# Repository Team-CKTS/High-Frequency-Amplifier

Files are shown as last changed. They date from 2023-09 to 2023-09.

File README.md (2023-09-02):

# High-Frequency-Amplifier
During our 3rd semester at the University of Moratuwa, we designed a High-Frequency Amplifier. Croos, Tharusha, Sasini, and Kumudu, who contribute to our team, were able to use their knowledge in circuit design, PCB design, and enclosure design to produce this device resulting in an amplifier capable of driving an 8-ohm load (speaker) without introducing any distortion to the output signal. It can amplify signals ranging from 20kHz to 100kHz, employing a two-stage amplifier approach with specific configurations.



What you can find here :
- Components
- Circuit Design
- PCB Design
- Enclosure Design
- Simulation Results

## Objective ##
The primary objective of this project is to design a high-frequency amplifier with the following specifications:
- **Load Compatibility:** Capable of driving an 8-ohm load (speaker) without causing distortion in the output signal.
- **Frequency Range:** Amplify signals within the frequency range of 20kHz to 100kHz.
- **Amplification Stages:** Utilize a two-stage amplifier approach. The first stage employs a transistor in the common emitter configuration, while the second stage uses an AB Push-Pull 
  amplifier configuration to achieve the necessary power amplification.

## Components ##
- BC547BG NPN BJT transistor
- TIP31C and TIP32C power transistors
- Capacitors, Resistors, Power resistors
- PCB
- Enclosure

## Circuit Design ##
Our circuit was design using **Multism**. It incorporates two amplifier stages. The first stage utilizes a transistor in the common emitter configuration, while the second stage employs an AB Push-Pull amplifier configuration. This combination ensures efficient high-frequency signal amplification.



## PCB Design ##
The PCB design we designed using **Altium Software**. It is essential for achieving reliable and precise circuit connections. It minimizes interference and supports efficient signal amplification. The "PCB design files" directory contains the PCB design files, which include:
- Schematic Design
- PCB Design
- Gerber files for manufacturing





## Enclosure Design ##
We designed an enclosure useing **Solidworks software**, to protecting the amplifier components.





## Contributors ##
- Croos : Circuit	design, Soldering	PCB, Breadboard	Implementation
- Tharusha : Circuit	design, PCB	design, Component Selection
- Sasini : Circuit	design, Enclosure design, Simulation	in Multisim
- Kumudu : Circuit design, Enclosure design, Documentation

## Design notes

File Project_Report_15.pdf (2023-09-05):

## Department of Electronic and Telecommunication Engineering University of Moratuwa

## EN2091 - Laboratory Practice and Projects


## High Frequency Amplifier

## Group 15

Croos J.J.S.E | 200095V
Kaushalya K.W.K | 200298V
Pathirana K.P.T.R | 200449L
Wanigathunga W.A.S.S | 200693D

Abstract

The design of a high frequency amplifier was the objective of this project. This should be able to drive an 8-ohm load(speaker) without causing any distortion to the output signal. It should be able to amplify signals of frequencies 20kHz-100kHz. There are two-stage amplifiers. The first stage uses a transistor in the common emitter configuration. The second stage uses an AB Push Pull amplifier configuration to achieve the power amplification needed to drive the speaker.
The amplifier achieved an open terminal voltage gain of around 20.4, and had a voltage gain of around 14.6 with a speaker.

## Contents

1 Introduction | 2
2 Methodology | 2
3 Results | 5
4 Individual contributions | 8
5 Conclusion | 8
6 References | 8
7 Appendices | 9

## 1 Introduction

This report outlines the challenge that has been assigned as well as the project’s objective requirements.

### 1.1 Objective

The given task is to design a high frequency amplifier with small amplitude loss or waveform distortion that can drive a small speaker. Design requirements for amplifier :

1. Bandwidth: 20 kHz - 100 kHz
2. Minimum number of transistors: 3
3. Operating voltage: < 12V
4. Input: 0.1Vp-p (MAX)
5. It should be able to drive 8 Ω (headphone) load without significant waveform distortion or amplitude reduction.

The parameters to be determined for the specifications sheet for the product :

1. Open Circuit Gain
2. Gain (with 8Ω load)
3. Bandwidth
4. Input Resistance
5. Output Resistance
6. Maximum Load Current

### 1.2 Summary of report

The High Frequency Amplifier design, development, and testing processes are covered in the report.
There are two stages of amplifier, a voltage amplification stage and a power amplification stage.
The amplifier circuit was first sketched up on paper, then it was simulated using Multisim, and then a physical prototype was created and tested using Altium.
Using data from testing performed on the final prototype, the final specifications sheet was created.

## 2 Methodology

The method used to create and design the amplifier is described in this section. Before examining the design method, the amplifier’s theory will be reviewed.

### 2.1 Amplifier Theory

In the market, amplifiers are frequently employed. They have many different applications. The amplification of audio signals before they are sent to speakers is one such application. Whereas the amplifier just has to be able to handle signals up to roughly 20kHz for typical applications dealing with music or voice. Nonetheless, some applications might call for amplification of higherfrequency signals. As a result, a high frequency amplifier’s design is important.

### 2.1.1 Amplifier Classes

Depending on their range of action, amplifiers can be divided into different classes.

### 2.1.2 Class A Amplifiers

The most popular amplifiers are class A amplifiers. They fully amplify the input signal and feature a basic structure. A constant current must flow through the transistor to bias it in a way that prevents it from turning off throughout the oscillation. Nevertheless, because of this characteristic, they are efficient and produce a lot of heat. They cannot, therefore, be applied for high power amplification applications.

### 2.1.3 Class B Amplifiers

Due to bias, only half of the input signal is conducted by class B amplifiers. The complete waveform can be obtained by using

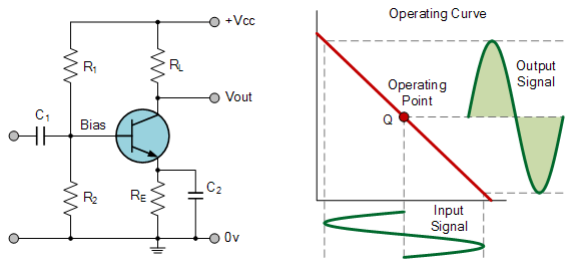
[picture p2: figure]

Figure 1: Class A amplifier

two of these amplifiers set up in a ”Push Pull” arrangement and combining the output signal.
As this amplifier’s quiescent current is 0, there is minimal or no DC current and hence significantly less power loss. Although the 0.7V needed to bias the transistor into the active region causes a small waveform distortion known as zerocrossing distortion, it is still present.

### 2.1.4 Class AB Amplifiers

By permanently bringing the two transistors just inside the active region, class AB amplifiers get over the distortion problem that plagues class B amplifiers. Although the efficiency is decreased, the output waveform is undistorted as a result.

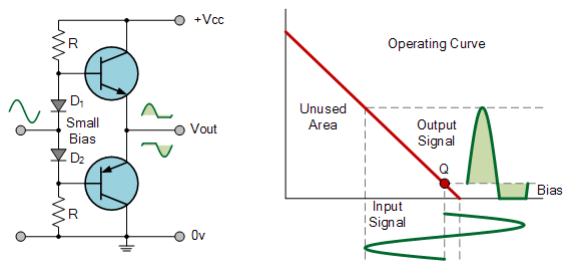
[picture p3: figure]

Figure 2: Block of circuit diagram

Although the power dissipation due to the DC component is substantially smaller than class A amplifiers, this is much more suitable for high power amplification applications.

### 2.2 Circuit Design

The design makes use of a cascading two-stage amplifier. Initially, a Bipolar Junction Transistor is used. It is applied in a common emitter arrangement. A capacitor is used to cascade the amplifier. Four BJTs set up in an AB push pull arrangement are used in the second stage.
The amplifier is cascaded as following manner:

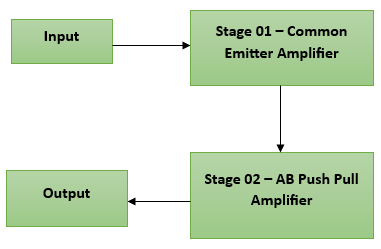
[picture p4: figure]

Figure 3: Block of circuit diagram

A 100µF capacitor connects the two stages in order to stop the transmission of Direct Current (DC) signals.
A 4.7µF capacitor and a small 2.2kΩ resistor are used to connect the input to stage one in order to reduce the distortions that were detected during testing.
For the same reason as previously, a 1000µF capacitor is used to connect the output. This is crucial because DC signals that are transmitted into speakers run the risk of doing so.

### 2.2.1 Stage 01 - Common Emitter

The objective of the first stage is getting a high voltage amplification. Then we decided to use class A common emitter amplifier for this purpose. We got 22 of voltage gain roughly. We used BC547BG transistor after comparing with others.
Higher bandwidth and fast switching, enabling it to handle high frequency signals are the main reasons to select this transistor.
The design of the first stage was determined as follows:

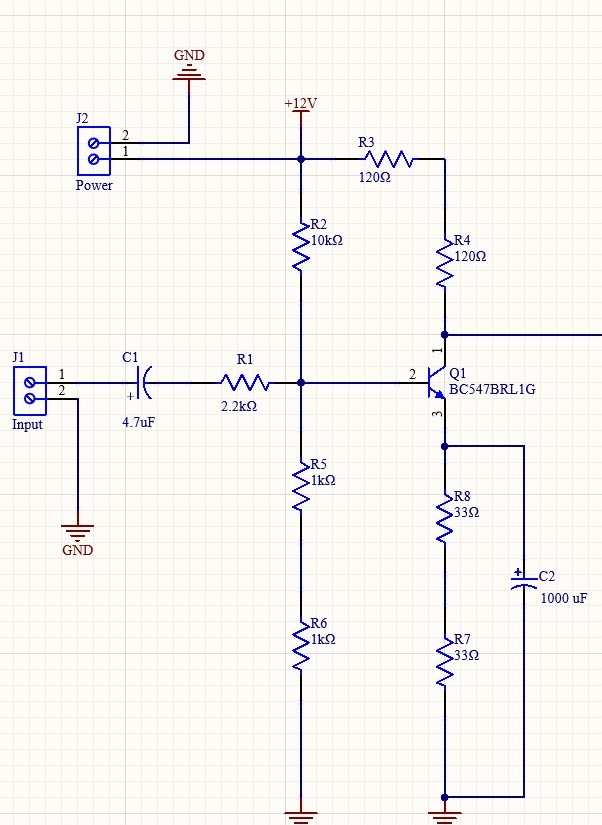
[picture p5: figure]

Figure 4: Stage 1 Circuit Diagram

- The base was biased at the base voltage is 2V. Therefore the base resistors, R2=10kΩ and R5=R6=1kΩ.
- VB = 2V. (Base current is negligible)
- VE = 1.3V. (Assuming VBE is equal to 0.7V)
- We selected the emitter resistor such that Ie ≈ 20 mA.
- Therefore, RE = 66Ω (R7 + R8), IC ≈ 20mA.
- VCE ≈ 6V.
- Therefore, RC =
12−7.3
20 kΩ ≈ 240Ω
(R3 + R4).

### 2.2.2 Stage 02 – AB Push Pull Am-

plifier

AB Push Pull stage is the second stage of amplifier. This stage is used to obtain the necessary power amplification for driving the 8 ohm load (speaker) without significantly reducing the output amplitude.
We made the decision to select the TIP 31C/TIP 32C power transistor pair after reviewing the datasheets. These transistors are capable of handling the high currents that are currently flowing through them and provide a sizable current gain.

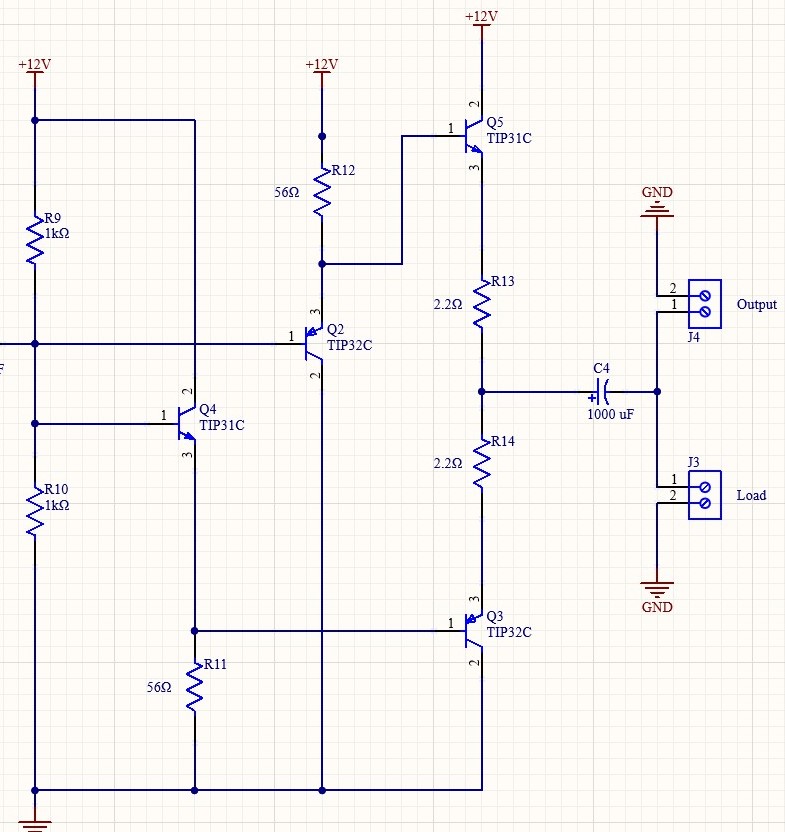
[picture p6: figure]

Figure 5: Stage 2 Circuit Diagram

Because of the high currents flowing through them, the 56Ω resistors are power resistors. The circuit has a large current gain but
a voltage gain of one, which is sufficient for the application.
To guarantee that no DC component reaches the output, the load is connected via a capacitor.

### 2.2.3 Initial Designs

An emitter follower amplifier was used in the early design of the amplifier to create three stages, including a middle current amplification stage. However, this step generated a distortion, and after it was removed, the voltage gain did not decrease. As a result, we choose to eliminate this stage. The base resistors’ initial values were substantially lower (1kΩ and 200Ω). However, when a load was attached, there was an input distortion because of the low input resistance. As a result, we multiplied the input resistors by 10.
Finally, when a load was connected, there was a small distortion of the output signal. We connected a 2.2kΩ resistor in series with the input coupling capacitor to solve this problem.

### 2.3 Prototype Design

Multisim, which was used to create the virtual prototype (see Appendix A), was the foundation for several of the testing. Using Altium, the PCB for the physical prototype was created (See Appendix B for layout). Following screen printing (Figure 6), the necessary parts were soldered to the PCB.

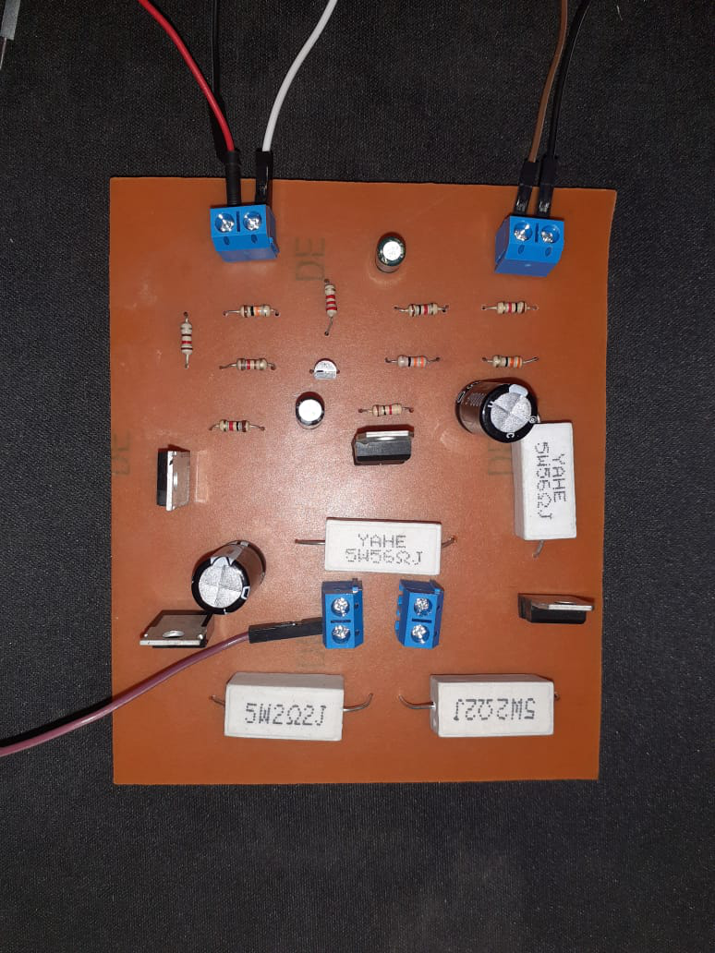
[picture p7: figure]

Figure 6: PCB

SolidWorks was used to create the Enclosure. To allow for heat dissipation and prevent the amplifier from overheating, the enclosure has a perforated cover (see Appendix C).

### 2.3.1 List of Components and Equip-

ment Used

The list of components used in the circuit:

1. BC547BG NPN BJT transistor
2. TIP31C power transistor (2)
3. TIP32C power transistor (2)
4. Heat Sinks (4)
5. Capacitors (4.7uF – 1, 100uF – 1, 1000uF – 2)
6. Resistors (33Ω - 2, 120Ω - 2, 1kΩ - 4, 10kΩ - 1, 2.2kΩ - 1)
7. Power resistors (56Ω - 2, 2.2Ω - 2)

The list of other components and equipment used in the development process:

1. Breadboard
2. Digital Multimeter
3. Power supply
4. Signal Generator
5. Digital Oscilloscope
6. 8Ω speaker
7. Connectors
8. Materials required for screen printing and soldering the PCB

## 3 Results

Three steps made up the evaluation of the amplifier, with the first step being the basic calculations made by hand during circuit design. The simulation of the circuit was second and the prototype was eventually constructed and tested.
Requirements and methods used to test:

### 3.1 Testing and Results

The design requirements were examined and the parameters required for the datasheet were obtained using the actual prototype and the simulation.
The methods of obtaining those parameters are given below.

Design Require-ment | Testing Method
Bandwidth | Simulation
Min No. of tran-sistors | Simulation / Cir-cuit Design
Operating Voltage | Initial Calcula-tions
Allowable Input Voltage | Prototype
Allowable load without distortion | Prototype
Data sheet | Prototype / Simu-lation

### 3.1.1 Initial Calculations

The Hybrid model was initially used to generate some of the parameters for stage one. However , lot of these parameters were eventually discarded because they did not match the observed values.
For the first stage:
Find rπ:

rπ =

VT
IB

=

26mV
20mA/300

= 390Ω

Input resistance:

Rin = Rb1//Rb2//rπ ≈ rπ = 390Ω

Open circuit voltage gain:

Avo ≈

β ∗ Rc

Rin

≈ 180 ≈ 22.55dB

### 3.1.2 Simulation

Multisim was used to simulate the amplifier circuit. The following are the parameters that the simulation obtained:

1. Open circuit gain - 18.986 dB The oscilloscope tool in Multisim was used to test the Open circuit gain. As seen in Figure 7, the value mentioned above is accurate for the mid frequency values.
2. Gain with 8Ω load - 17.167dB By placing an 8Ω load across the output, the gain with an 8Ω load was

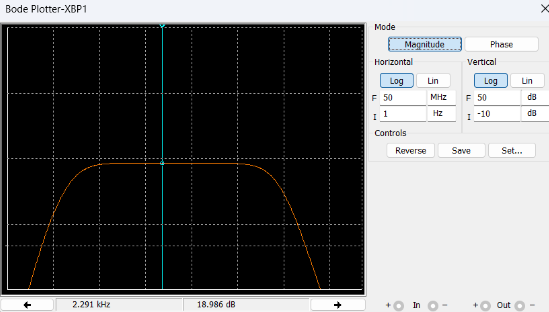
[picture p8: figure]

Figure 7: Bode plot of simulated circuit

evaluated. Then the oscilloscope tool was used to test the gain.

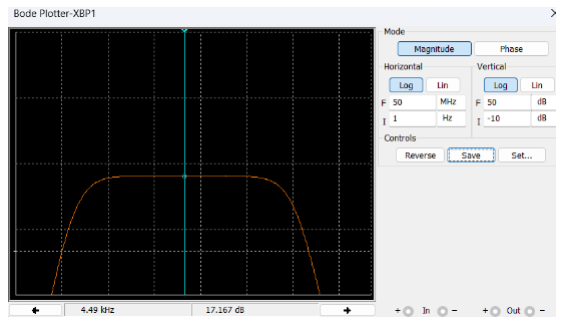
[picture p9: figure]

Figure 8: Bode plot of simulated circuit with 8Ω load

3. Bandwidth – 19.302 Hz to 1.117 MHz
The bode plotter tool which is available in the Multism was used to test the bandwidth of amplifier. Cutoff frequencies were taken as the half power points.
4. Input Resistance – 2.772kΩ
The multimeter was used to test the input resistance for measure the current drawn from the source.
5. Output Resistance – 8.44Ω
The input circuit was shorted to measure the output resistance. Then connecting a current source across the output and using the multimeter to measure the voltage across the output.
6. Maximum Load Current
– 31.6mA (for 8Ω load)

The multimeter was used to measure the current through the load

### 3.1.3 Tested Circuit

The Prototype Amplifier was tested, and the results revealed the following useful parameters.

1. Open Circuit Voltage Gain
– 13.096dB
By attaching the input and output to an oscilloscope and determining the voltage gain between the two, the open circuit gain was evaluated. The voltage gain was evaluated for frequencies between 20Hz and 100kHz, and the value above is the highest voltage gain that was consistently present throughout the mid-frequency ranges.

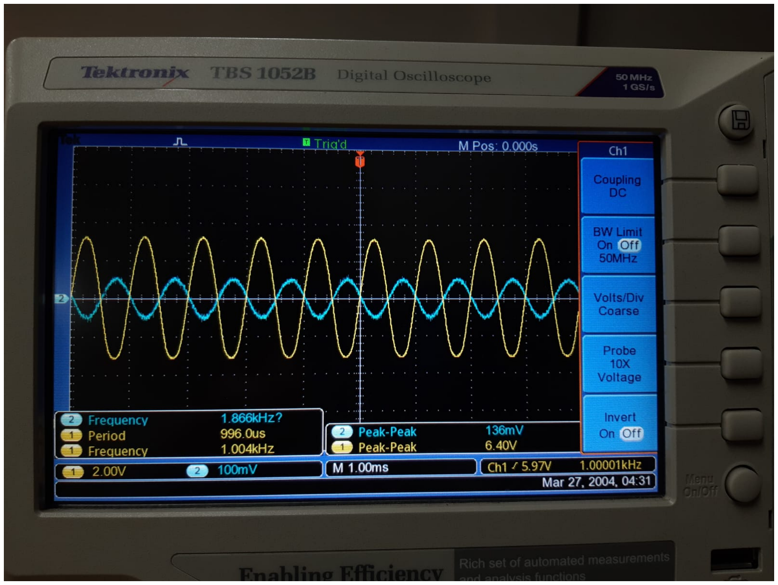
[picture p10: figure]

Figure 9: Output waveform with 8 Ω load

2. Gain (with 8Ω load) – 11.64dB The same procedure as before was used to test the voltage gain with an 8-volt load attached across the output.
3. Bandwidth – 18.986Hz to 1.087MHz The half power value(14dB) was obtained as the circuit’s gain.
Until the gain dropped to 14dB, the upper and lower cutoff values were calculated by slowly changing the input frequency.
The lower cutoff frequency does not adhere to the design specifications, although the upper cutoff frequency complies.
4. Input Resistance – 2.3kΩ
An ammeter was used to measure the current drawn from the input for an input voltage of 0.1V (peak to peak), with the output open circuited, in order to estimate the input resistance. The input resistance was then calculated by dividing the peak voltage (0.05V) by the peak current.
5. Output Resistance – 7.9Ω
Two ways were used to determine the output resistance. First, we steadily decreased the load starting at 8Ω until the amplifier’s gain fell to half its initial value. This occurred with a load resistance that is equal to the output voltage.
The following equation was applied for a few different load resistances in order to validate this result:

Rout =

Ao ∗ RL
A

− RL

RL = Load resistance
Ao = Open circuit voltage gain
A = Gain with given load resistance
6. Maximum Load Current – 28mA (for 8Ω load)
Connecting an ammeter through the load and measuring the output current for a 0.1V peak to peak input signal to determine the maximum load current.

## 4 Individual contributions

Croos J.J.S.E | Circuit design, Soldering PCB, Breadboard Im-plementation
Kaushalya K.W.K | Circuit design, Documentation
Pathirana K.P.T.R | Circuit design, PCB design, Component Selec-tion
Wanigathunga W.A.S.S | Circuit design, Enclosure design, Simulation in Multisim

## 5 Conclusion

Within the allotted time, we succeeded in finishing this project.
The amplifier falls short of entirely satisfying the bandwidth requirement. The lower cutoff(20kHz) is significantly lower than the specified requirement even though it satisfies the upper cutoff requirement (100kHz).

### 5.1 Discussion

- While driving a small load, the amplifier does not significantly lose gain or distortion.
- Within the specified bandwidth, there is a minor waveform distortion at all frequencies. This indicates an excessively high Total Harmonic Distortion.
- The values received during the simulation did not match the values obtained from the calculations.
- The TIP transistors produce a lot of heat that is dispersed. To prevent burning, heat sinks have been affixed to the amplifiers. In order to make sure that they can withstand the high currents flowing through them, power resistors have also been used.
- The simulation’s settings came near to, but weren’t exactly, the final values discovered after testing the physical prototype. The specification sheet, however, was created using prototype values. As a result, the performance of the amplifier will be accurately represented on the specification sheet.

## 6 References

- Amplifier classes -
https://www.electronics-tutorials.ws/amplifier/amplifier-classes.html (https://www.electronics-tutorials.ws/amplifier/amplifier-classes.html)
- BC546/547 Datasheet -
https://www.sparkfun.com/datasheets/Components/BC546.pdf (https://www.sparkfun.com/datasheets/Components/BC546.pdf)
- TIP31C Datasheet -
https://www.st.com/resource/en/datasheet/tip31c.pdf (https://www.st.com/resource/en/datasheet/tip31c.pdf)
- TIP32C Datasheet -
https://www.st.com/resource/en/datasheet/tip32c.pdf (https://www.st.com/resource/en/datasheet/tip32c.pdf)
- 2N2222 Datasheet -
https://www.farnell.com/datasheets/296640.pdf (https://www.farnell.com/datasheets/296640.pdf)

## 7 Appendices

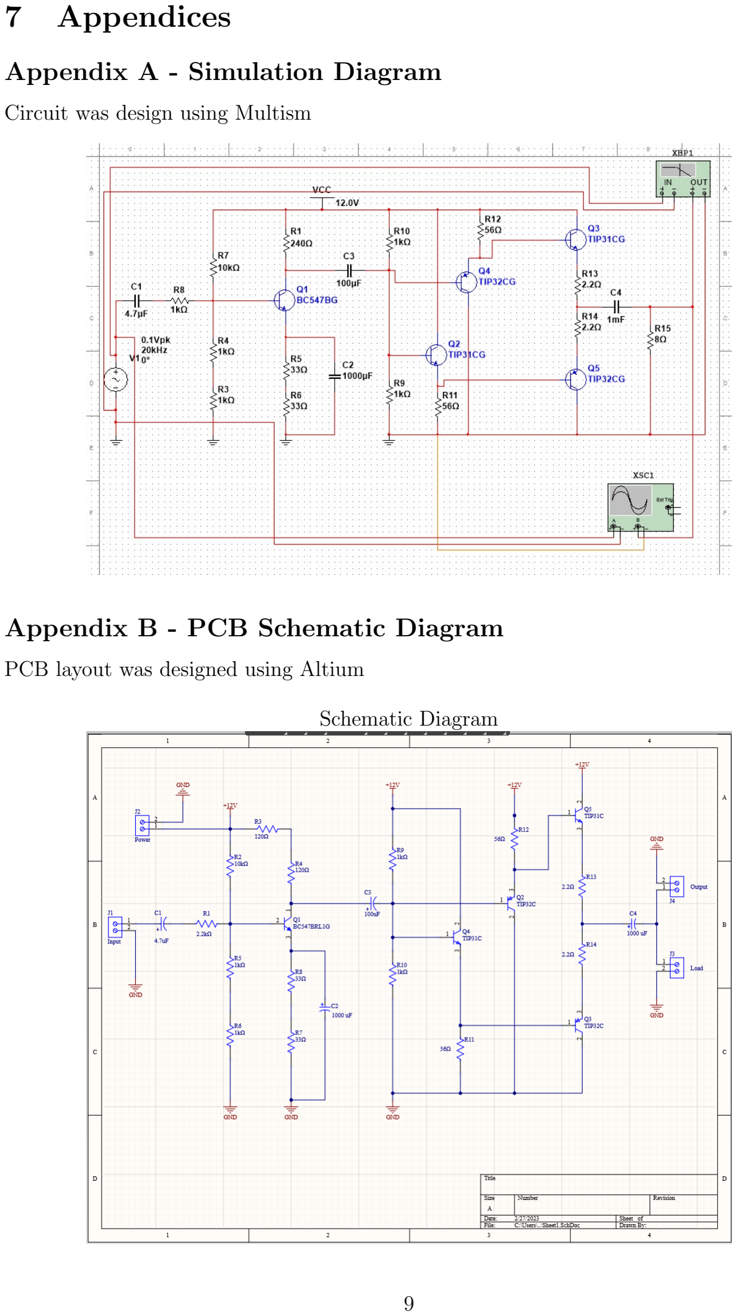
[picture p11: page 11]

### Appendix A - Simulation Diagram

Circuit was design using Multism

### Appendix B - PCB Schematic Diagram

PCB layout was designed using Altium

Schematic Diagram

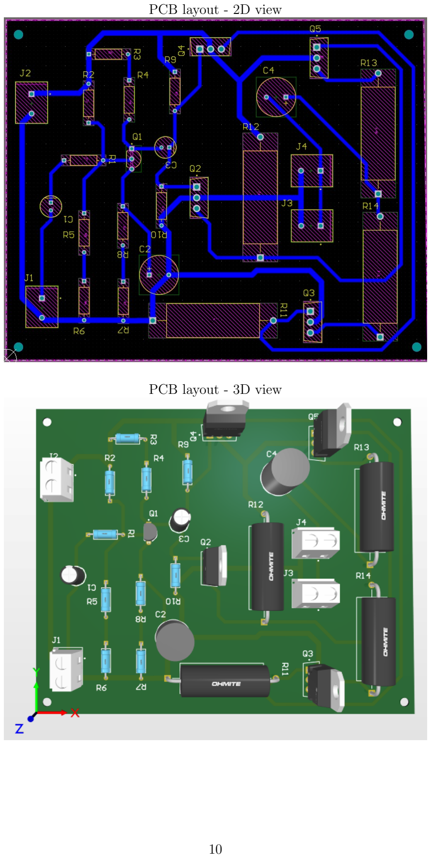
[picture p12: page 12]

PCB layout - 2D view

PCB layout - 3D view

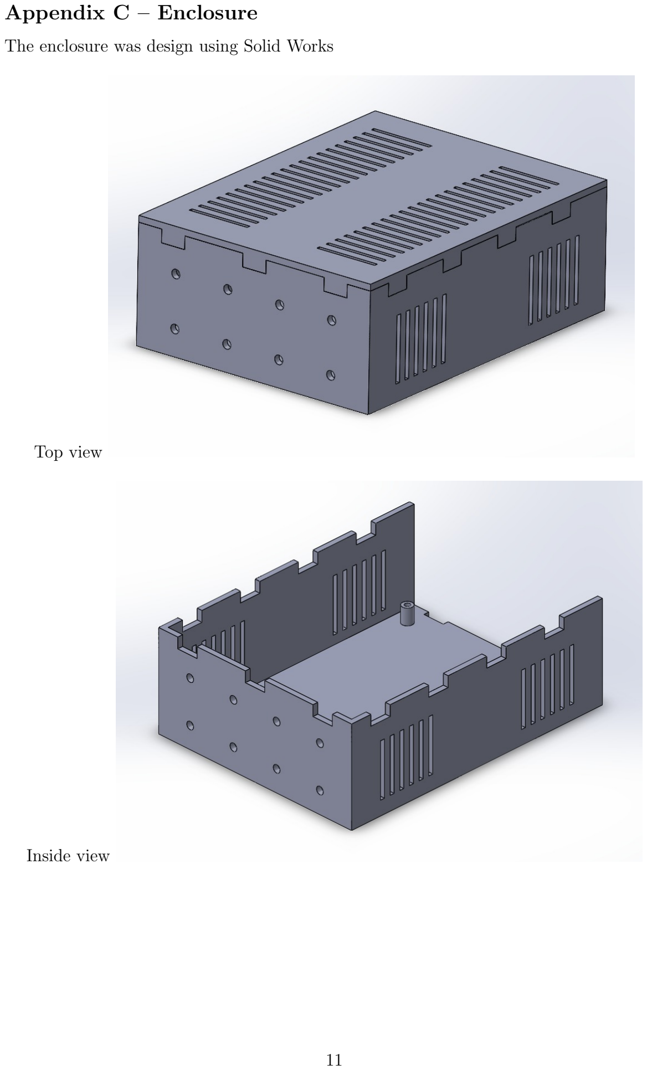
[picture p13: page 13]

### Appendix C – Enclosure

The enclosure was design using Solid Works

Top view

Inside view

### Testing and Breadboard Implementation

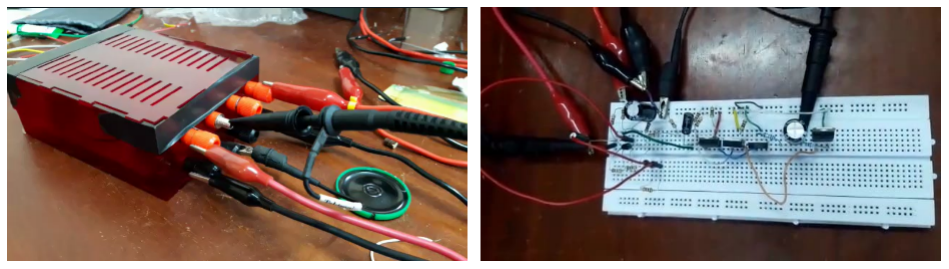
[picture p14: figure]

### Final Product

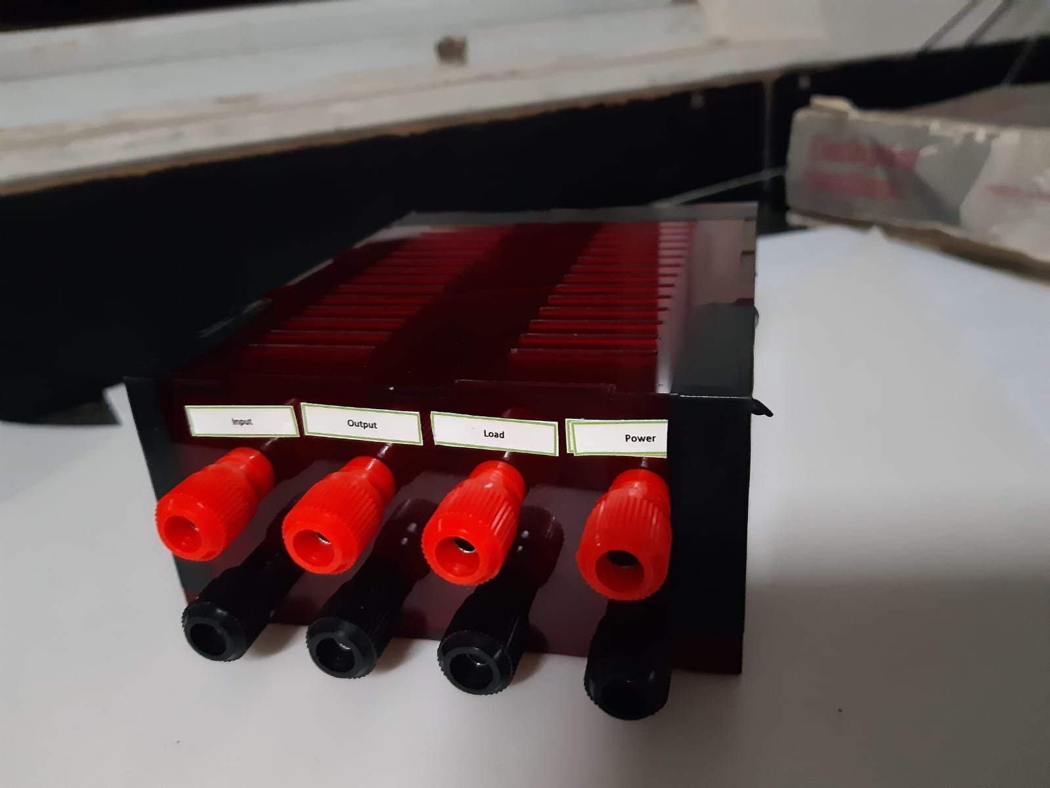
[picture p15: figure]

### Appendix D – Specification Sheet

## HIGH FREQUENCY AMPLIFIER Specification Sheet

- Description
The High Frequency Amplifier is an amplifier that can be used for high frequency applications. The design enables the amplifier to drive a small load, making it ideal for amplification of audio signals etc.
- Functional Block Diagram

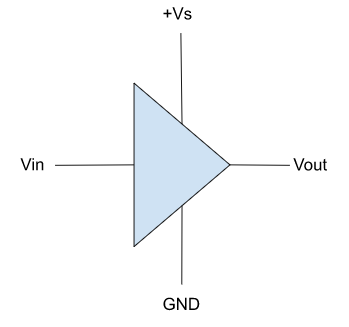
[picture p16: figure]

- Electrical Specifications
Parameter | Conditions | Minimum | Typical | Maximum | Units
Operating Supply Voltage | - | - | - | 12 | V
Input Voltage (pk-pk) | Sine wave | - | - | 0.1 | V
Open Circuit Voltage Gain | RL → ∞ | - | 18.986 | - | dB
Voltage Gain | RL → 8Ω | - | 17.167 | - | dB
Bandwidth | - | - | 1.117 | - | MHz
Power Output | RL → 8Ω | - | 7.97 | - | mW
Input Resistance | RL → ∞ | - | 2.787 | - | kΩ
Output Resistance | Vs=0V | - | 7.975 | - | Ω
Load Current | RL → 8Ω | - | 31.6 | - | mA

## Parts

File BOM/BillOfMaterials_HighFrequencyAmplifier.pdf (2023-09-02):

# Bill Of Materials

Item | Qty | Price (Rs.)
BC547BG NPN BJT transistor | 1 | 5.00
TIP31C power transistor | 2 | 160.00
TIP32C power transistor | 2 | 240.00
Heat Sinks | 4 | 260.00
Terminal Blocks | 4 | 180.00
Capacitors (4.7uF – 1, 100uF – 1, 1000uF – 2) | 4 | 50.00
Resistors (33Ω - 2, 120kΩ - 2, 1kΩ -4, 10kΩ - 1, 2.2kΩ - 1) | 10 | 50.00
Power resistors (56Ω - 2, 2.2Ω - 2) | 4 | 100.00
8Ω speaker | 1 | 50.00
PCB | 1 | 800.00
Banana Jacks | 8 | 520.00
Enclosure | 1 | 1300.00
Total | | 3715.00

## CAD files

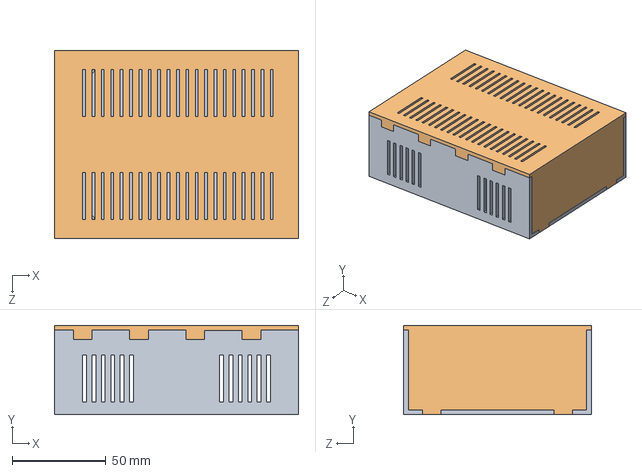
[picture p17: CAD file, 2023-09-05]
Enclosure/Assembly.SLDASM
130.0 x 47.5 x 100.0 mm

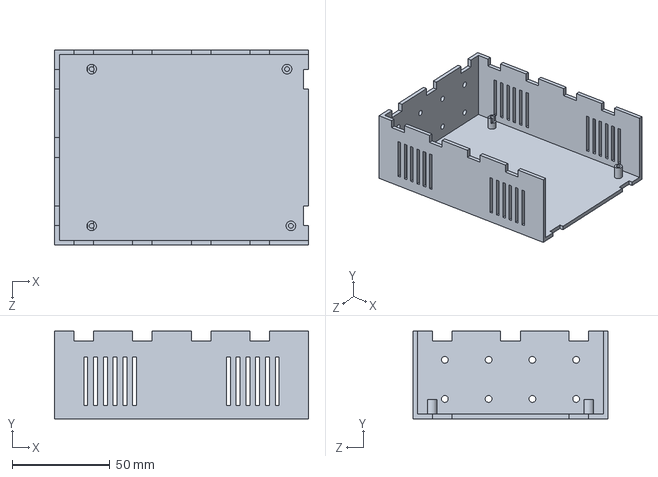
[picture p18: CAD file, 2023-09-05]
Enclosure/Part2.SLDPRT
130.0 x 45.0 x 100.0 mm

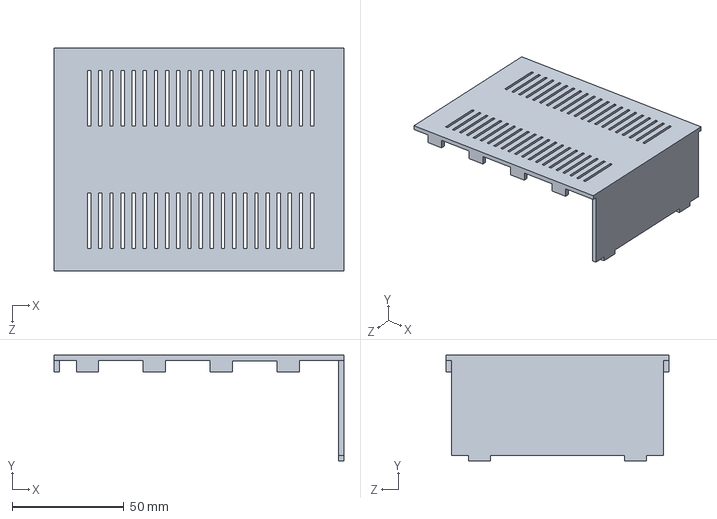
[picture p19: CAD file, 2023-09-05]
Enclosure/Part1.SLDPRT
130.0 x 47.5 x 100.0 mm

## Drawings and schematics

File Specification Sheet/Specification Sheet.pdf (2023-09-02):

# HIGH FREQUENCY AMPLIFIER

## Specification Sheet

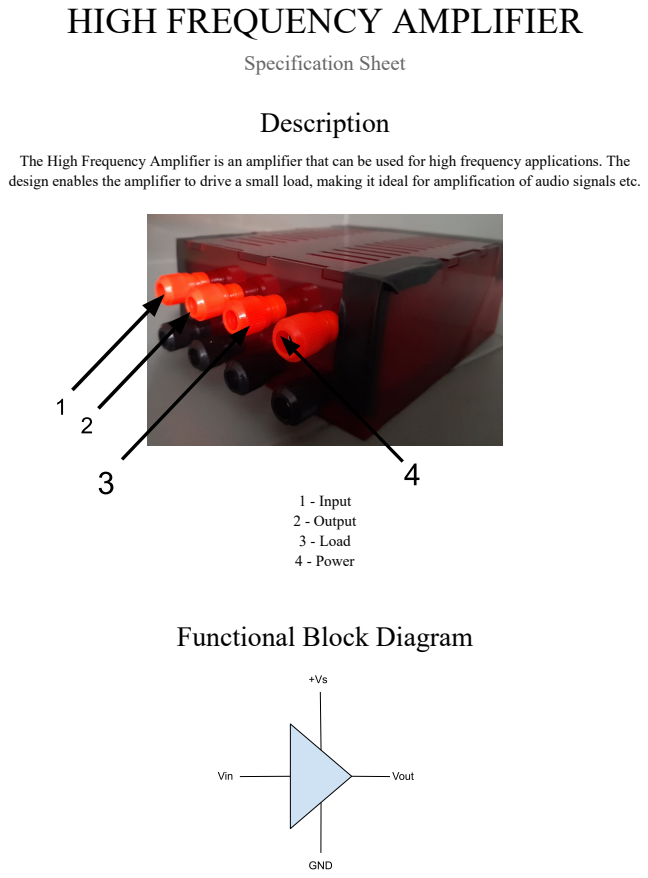
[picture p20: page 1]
Description; 1 - Input 2 - Output 3 - Load 4 - Power

The High Frequency Amplifier is an amplifier that can be used for high frequency applications. The
design enables the amplifier to drive a small load, making it ideal for amplification of audio signals etc.

Functional Block Diagram

# Electrical Specifications

Parameter | Conditions | Minimum | Typical | Maximum | Units
Operating Supply Voltage | - | - | - | 12 | V
Input Voltage (pk-pk) | Sine wave | - | - | 0.1 | V
Open Circuit Voltage Gain | R → ∞ L | - | 13.096 | - | dB
Voltage Gain | R L = 8Ω | - | 11.64 | - | dB
Bandwidth | - | - | 1.117 | - | MHz
Power Output | R L = 8Ω | - | 7.97 | - | mW
Input Resistance | R → ∞ L | - | 2.772 | - | kΩ
Output Resistance | Vs = 0V | - | 8.44 | - | Ω
Load Current | R L = 8Ω | - | 31.6 | - | mA

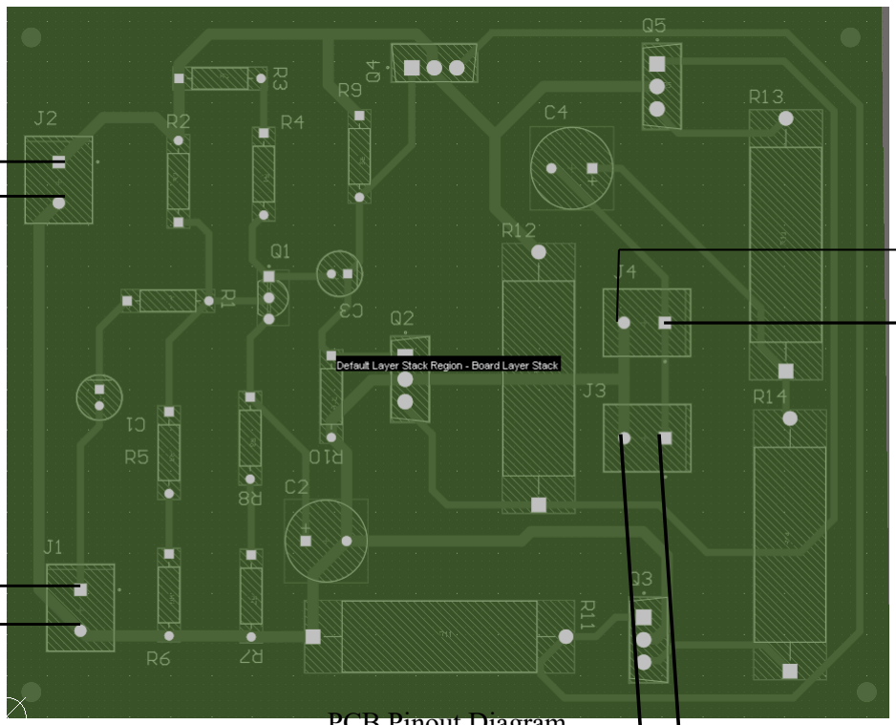
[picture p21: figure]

PCB Pinout Diagram

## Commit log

2023-09-03 Added PCB
2023-09-05 Create Enclosure Design
